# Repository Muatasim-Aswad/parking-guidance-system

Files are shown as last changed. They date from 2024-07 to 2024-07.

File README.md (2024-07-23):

# Parking Guidance System

The recent technological developments accompanied by economic changes have made affording an automobile easier and consequently led to a rapid increase in their numbers. Simultaneously, the usage of parking lots has increased. This increase is also concentrated due to people's tendency to populate certain small areas for different factors. For instance, in 2014 alone, 4 million cars parked in the ISPARK parking lot in the Fatih district/Istanbul. Usually, drivers do not directly find available parking spots and spend on average 7.8 to 10 minutes searching for them. Additionally, in large car parks, the driver might confront difficulties in finding the location of their parked car. This problem has adverse economic, environmental, and psychological effects. In the USA, the annual average time loss per driver during this process is 17 hours. Every time it costs a driver in France or the UK 1.42 Euro. The resulting emissions of CO2, CO, HC, and NOx are respectively 398.71, 19.90, 3.29, and 21.14 g/s/vehicle.

## The Design

As a solution to this problem, a prototype Parking Guidance System has been developed through the following. A conceptual design that addresses the system’s objectives, functions, guidance levels, and main components was prepared. The main criterion was to design a system that is more economical, less complex, flexible, scalable, and possible to improve while being acceptably efficient.

### System Components

- **Controller:** Arduino Mega (ATmega2560)
- **Sensors:** Ultrasonic sensors
- **Communication:** NodeMcu 12E (ESP8266) for Wi-Fi communication
- **User Interface:** Blynk IoT platform
- **Indicators:** Red and green LEDs, and an LCD 16x2

[Here](./drawings/fritzing/components-list.md) is the detailed list of the components.

The flow charts, block, pictorial, and schematic diagrams is used to describe the system processes, physical components, wiring, and their interactions. The code is written in Arduino IDE – C++ and preceded by flow charts that show all the functions and decision trees in the system software. Before successfully implementing the system, it was partially tested in a simulation environment, [Proteus](./drawings/proteus/) and [Wokwi](https://wokwi.com/projects/333014911768592980).

#### System Block Diagram

block diagram

#### System Flow Chart

flowchart

### Prototype Details

The prototype contains:

- 3 parking spaces with lamps
- A gate with a screen
- A website and an application through an IoT platform

The driver can see which spots are available in the parking lot through the screen, the app, and the website. While inside, they will be guided through the green lamps. Once the car is parked, the name (ID) of the car is assigned to the filled space. The ID can be chosen by the user through the Internet user interface (UI), otherwise, it would be chosen automatically by the system. Later the driver can locate his car by searching on the UI using the ID.

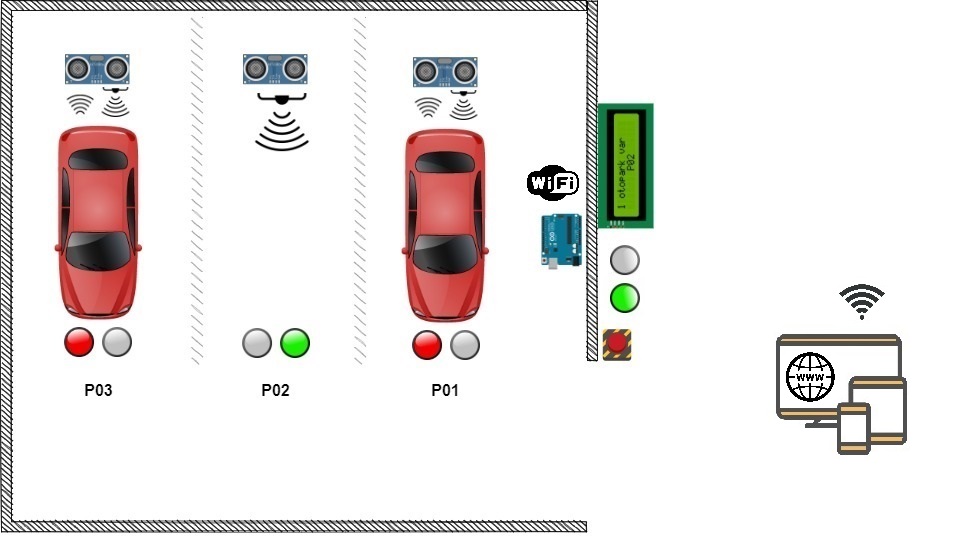
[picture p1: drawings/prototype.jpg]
prototype


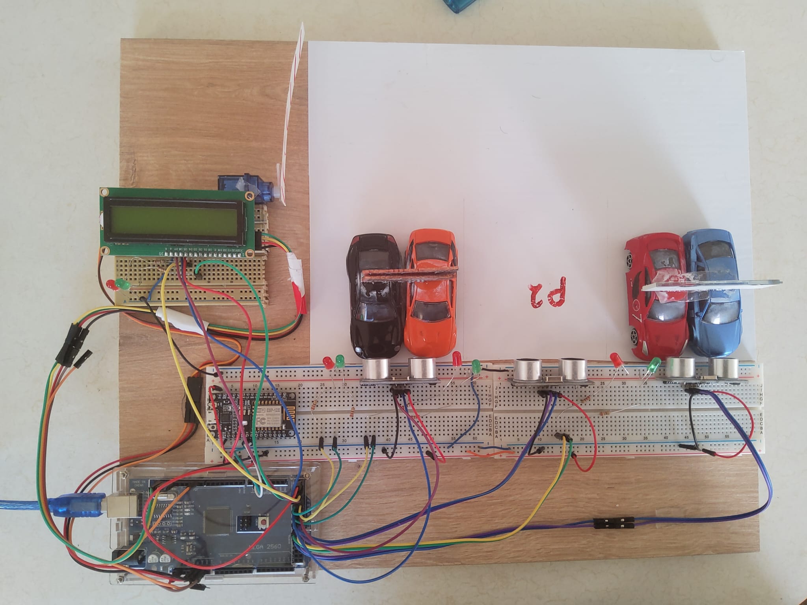
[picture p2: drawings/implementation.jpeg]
implementation


### Wiring

#### Pictorial Diagram

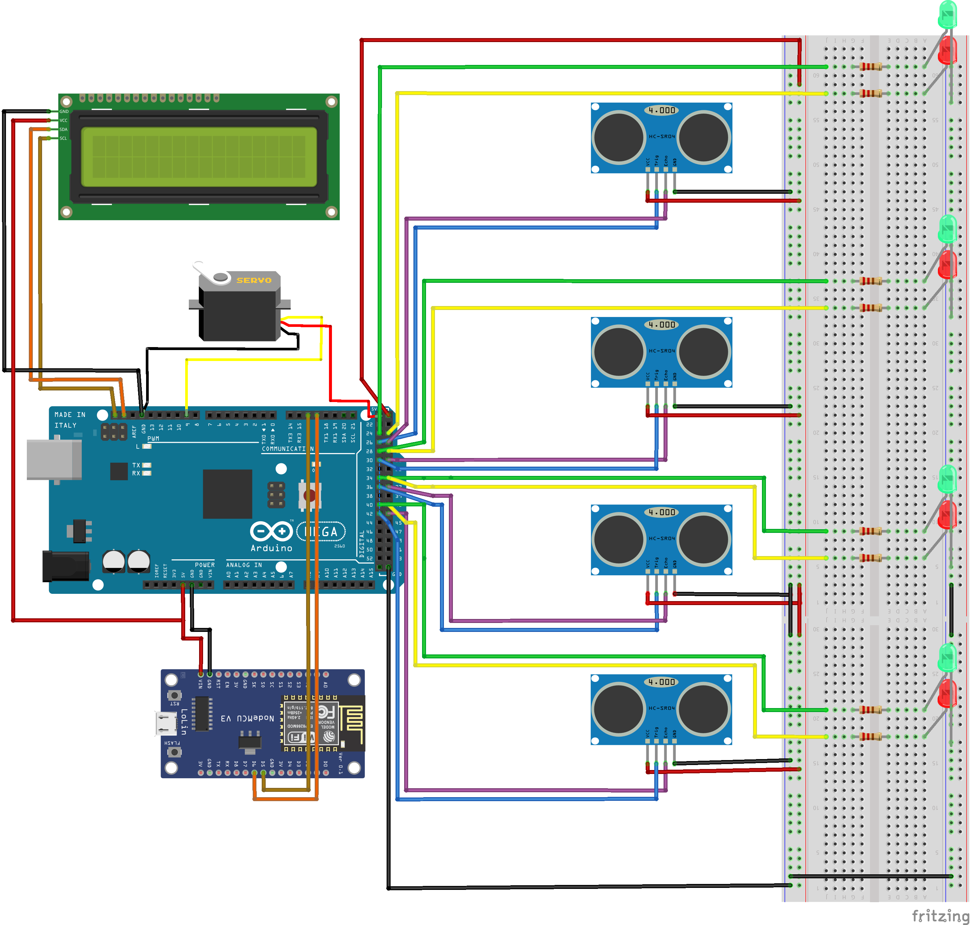
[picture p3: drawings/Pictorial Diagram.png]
Pictorial Diagram


#### Schematics - wires

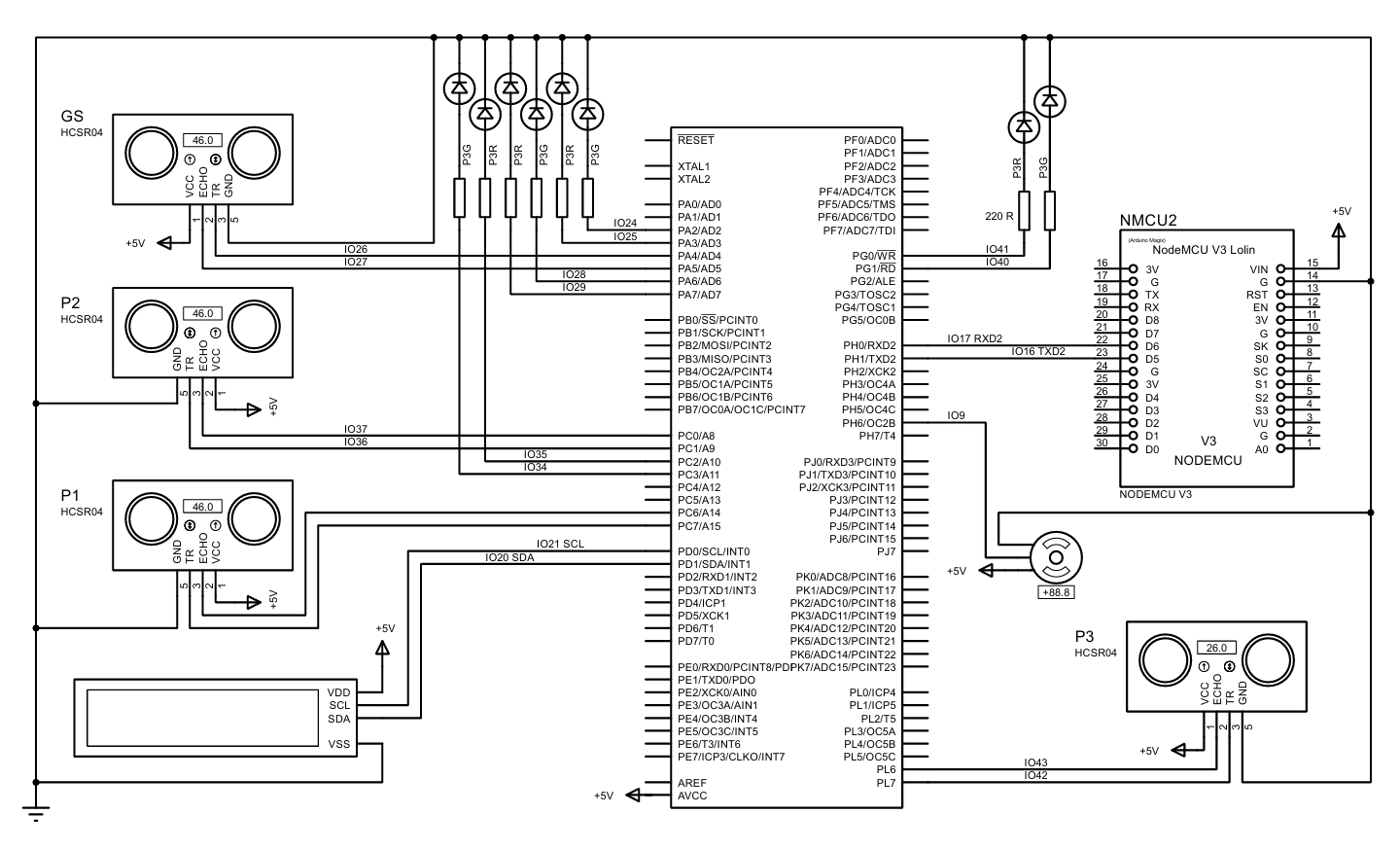
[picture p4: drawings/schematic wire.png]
Schematics - wires


#### Schematics - nodes

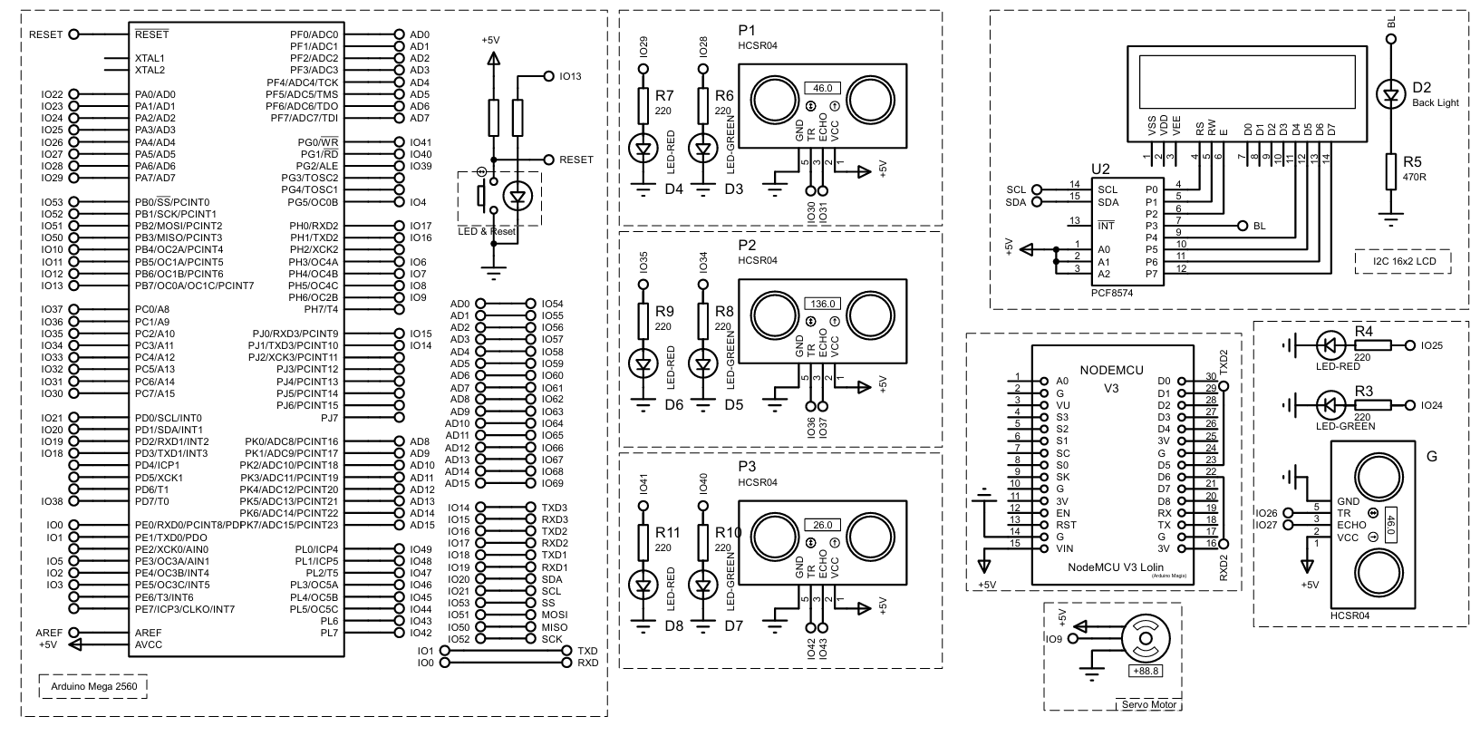
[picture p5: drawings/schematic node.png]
Schematics - nodes


### Future Improvements

- **Environmental Adaptation:** Sensors working with signals other than sound waves might be added to the already used sensors.
- **Automatic ID Registration:** Installing a plate reader on the gates to register the car number as its ID.
- **Enhanced Algorithm:** Improving the algorithm that assigns the car ID to the filled space for more accurate results.
- **User Interface Development:** Expanding the Internet user interface to include more features that benefit users on both sides, the owner, and the consumer.
- **City-Wide Guidance:** Integrating the system into a more comprehensive platform to guide the driver in larger areas, such as a whole city.
- **AI Integration:** Using AI algorithms to provide predictions about parking space availability and analyze user behavior.

### Ethical Considerations

The huge flow of data in automation processes dealing directly with consumers comes with the risk of violating user privacy. Therefore, adhering to ethical standards and legal regulations is essential for user rights. The implementation of these requirements should be observed and assured by the legal authorities.

## References

1. İSPARK, «Otoparklar her gün yoğun,» 6 Ocak 2015. [Çevrimiçi]. Available: [İspark](https://ispark.istanbul/)
2. O. Dokur, S. Katkoori and N. Elmehraz, «Embedded system design of a real-time parking guidance system,» Annual IEEE Systems Conference (SysCon), pp. 1-8, 2016.
3. Nandyal, Suvarna, Sabiya Sultana, and Sadaf Anjum., «Smart car parking system using arduino uno.,» International Journal of Computer Applications, no. 169.1, pp. 13-18, 2017.
4. Varan, Metin, and Ceylan Karakuş., «Sakarya şehri için dış ve iç yönlendirmeli rezervasyon tabanlı otopark yönetim sistemi tasarımı ve sistem başarımı,» Sakarya Üniversitesi Fen Bilimleri Enstitüsü Dergisi, cilt 1, no. 22, pp. 66-74, 2018.
5. P. D. M. Öztürk, «Otopark planlamasız şehirleşme olmaz,» 28 Şubat 2020. [Çevrimiçi]. Available: [Indyturk](https://www.indyturk.com/)
6. Dogaroglu, Bora, S. Pelin Caliskanelli, and Serhan Tanyel, «Comparison of intelligent parking guidance system and conventional system with regard to capacity utilisation.,» Sustainable Cities and Society, cilt 74, p. 103152, 2021.
7. Zhou, Fengli and Li, Qing, «Parking Guidance System Based on ZigBee and Geomagnetic Sensor Technology,» 2014 13th International Symposium on Distributed Computing and Applications to Business, Engineering and Science, pp. 268-271, 2014.
8. S.-e. Y. e. al, «PGS: Parking Guidance System based on wireless sensor network,» 2008 3rd International Symposium on Wireless Pervasive Computing, pp. 218-222, 2008.
9. H. V. Jaurkar, G. N. Mulay and V. Gohokar, «Parking guidance system using Internet of Things,,» International Conference on Inventive Computation Technologies (ICICT), cilt 1, pp. 1-6, 2016.
10. Huang, K. Y. and Chang, S. B. and Tsai, P. R., «The advantage of the arduino sensing system on parking guidance information systems,» 2017 IEEE International Conference on Industrial Engineering and Engineering Management (IEEM), Cilt %1 / %22078-2082, 2017.

## License

This is part of a project during my BSc in Mechatronics.

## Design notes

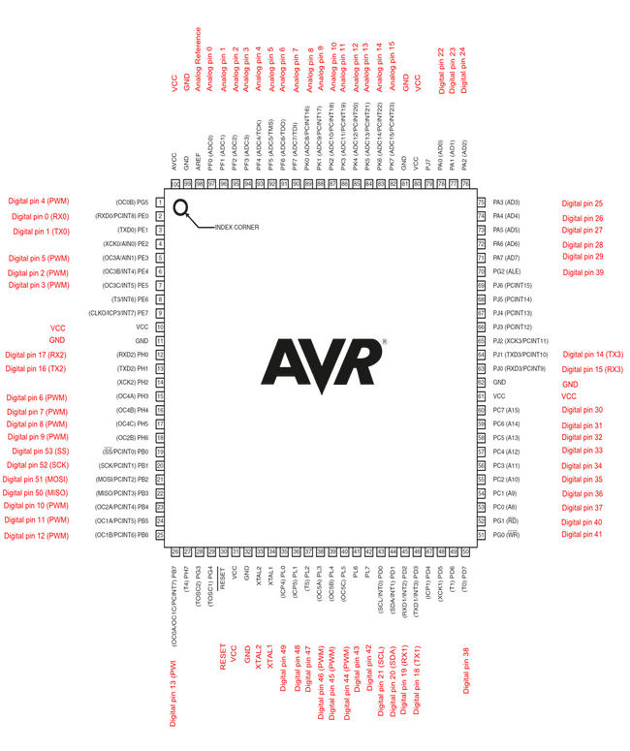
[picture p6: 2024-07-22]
datasheets/PinMap2560big_Rev2.png

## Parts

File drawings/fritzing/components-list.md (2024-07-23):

# Bill of Materials: otopark.fzz

*C:/Users/malas/Downloads/Bitirme/Fritzing/otopark.fzz*  
*Sunday, June 5 2022, 14:00:10*

## Assembly List

| Label | Part Type | Properties |
|---|---|---|
| hc-sr2 | hc-sr04 | variant hc-sr04 |
| hc-sr3 | hc-sr04 | variant hc-sr04 |
| hc-sr4 | hc-sr04 | variant hc-sr04 |
| hc-sr5 | hc-sr04 | variant hc-sr04 |
| J1 | Basic Servo |  |
| LED2 | Green (570nm) LED | color Green (570nm); leg yes; package 5 mm [THT] |
| LED3 | Red (635nm) LED | color Red (635nm); leg yes; package 5 mm [THT] |
| LED4 | Red (635nm) LED | color Red (635nm); leg yes; package 5 mm [THT] |
| LED5 | Green (570nm) LED | color Green (570nm); leg yes; package 5 mm [THT] |
| LED6 | Red (635nm) LED | color Red (635nm); leg yes; package 5 mm [THT] |
| LED7 | Green (570nm) LED | color Green (570nm); leg yes; package 5 mm [THT] |
| LED8 | Red (635nm) LED | color Red (635nm); leg yes; package 5 mm [THT] |
| LED9 | Green (570nm) LED | color Green (570nm); leg yes; package 5 mm [THT] |
| Part1 | Arduino Mega 2560 (Rev3) | type Arduino MEGA 2560 (Rev3) |
| Part2 | LCD1602-I2C | variant variant 1; pins 4; type Character |
| R1 | 220Ω Resistor | tolerance ±5%; package 2010 [SMD]; resistance 220Ω |
| R2 | 220Ω Resistor | tolerance ±5%; package 2010 [SMD]; resistance 220Ω |
| R3 | 220Ω Resistor | tolerance ±5%; package 2010 [SMD]; resistance 220Ω |
| R4 | 220Ω Resistor | tolerance ±5%; package 2010 [SMD]; resistance 220Ω |
| R5 | 220Ω Resistor | tolerance ±5%; package 2010 [SMD]; resistance 220Ω |
| R6 | 220Ω Resistor | tolerance ±5%; package 2010 [SMD]; resistance 220Ω |
| R7 | 220Ω Resistor | tolerance ±5%; package 2010 [SMD]; resistance 220Ω |
| R8 | 220Ω Resistor | tolerance ±5%; package 2010 [SMD]; resistance 220Ω |
| U1 | ESP8266 NodeMCU LoLin module | type ESP8266 NodeMCU LoLin |

## Shopping List

| Amount | Part Type | Properties |
|---|---|---|
| 4 | hc-sr04 | variant hc-sr04 |
| 1 | Basic Servo |  |
| 4 | Green (570nm) LED | color Green (570nm); leg yes; package 5 mm [THT] |
| 4 | Red (635nm) LED | color Red (635nm); leg yes; package 5 mm [THT] |
| 1 | Arduino Mega 2560 (Rev3) | type Arduino MEGA 2560 (Rev3) |
| 1 | LCD1602-I2C | variant variant 1; pins 4; type Character |
| 8 | 220Ω Resistor | tolerance ±5%; package 2010 [SMD]; resistance 220Ω |
| 1 | ESP8266 NodeMCU LoLin module | type ESP8266 NodeMCU LoLin |

*Exported with Fritzing 0.9.3 - [http://fritzing.org](http://fritzing.org)*

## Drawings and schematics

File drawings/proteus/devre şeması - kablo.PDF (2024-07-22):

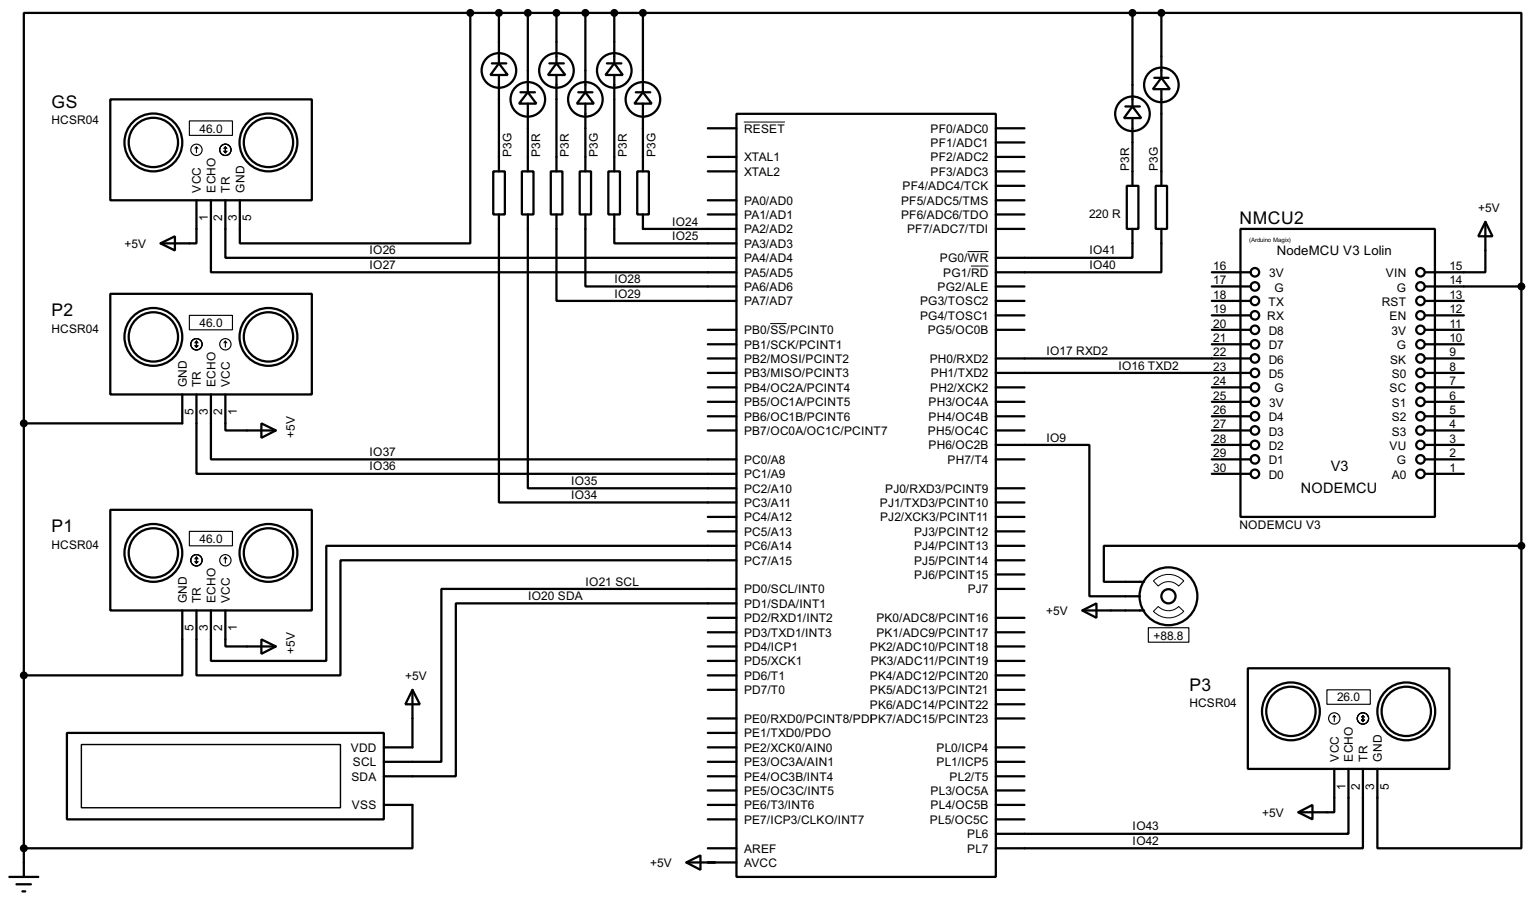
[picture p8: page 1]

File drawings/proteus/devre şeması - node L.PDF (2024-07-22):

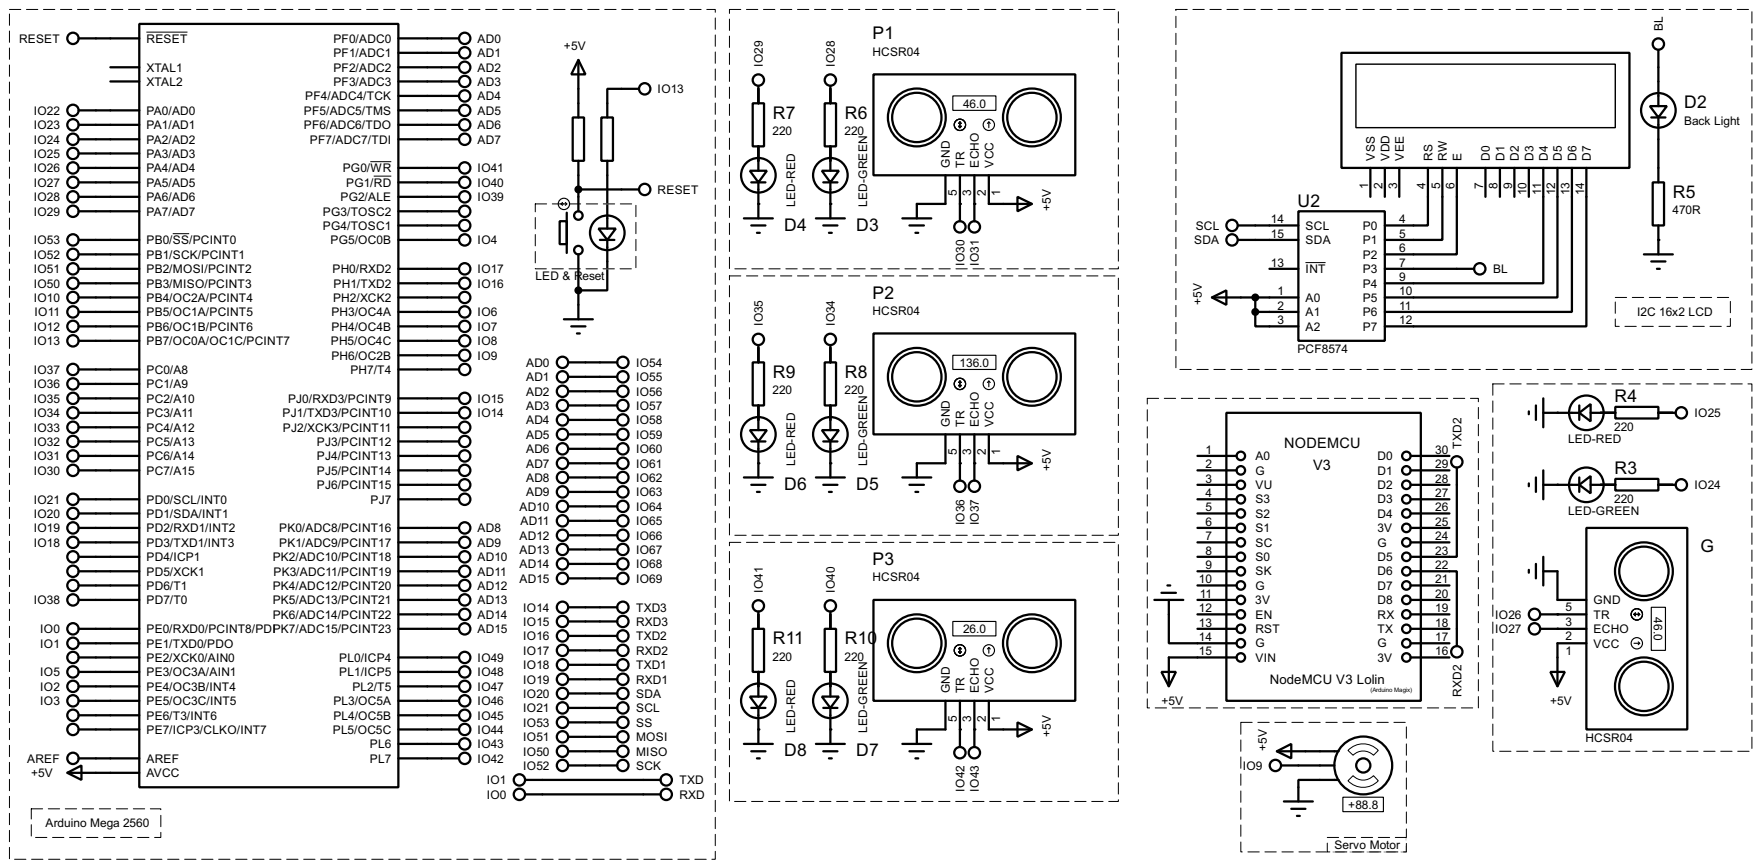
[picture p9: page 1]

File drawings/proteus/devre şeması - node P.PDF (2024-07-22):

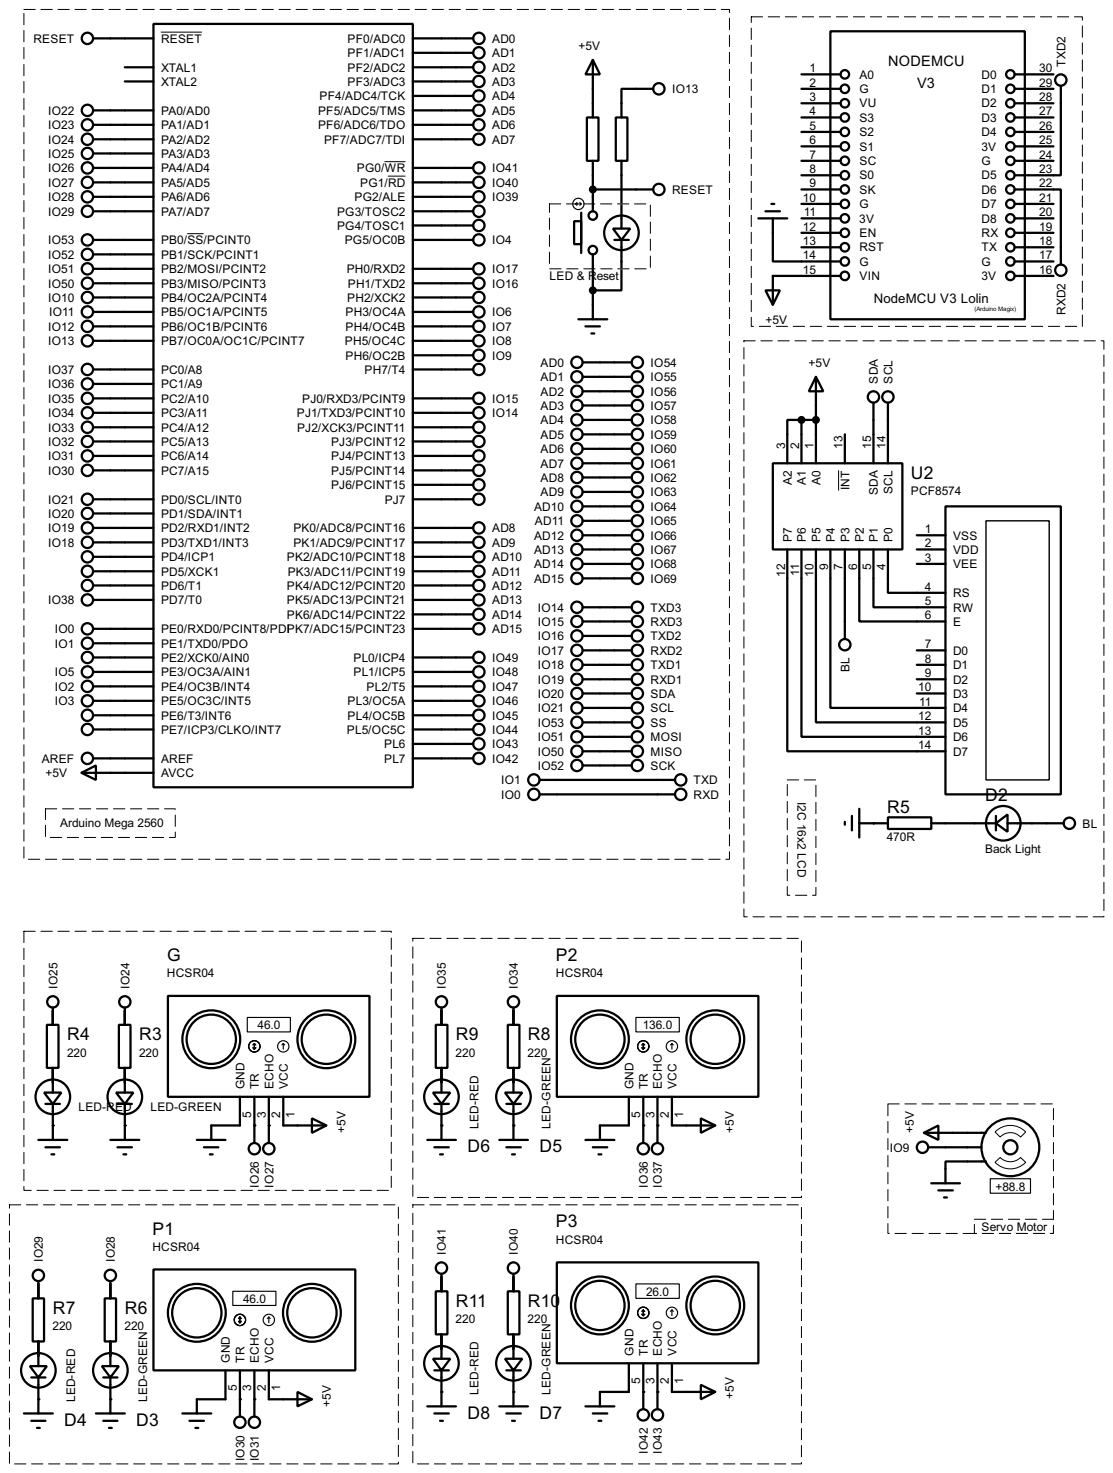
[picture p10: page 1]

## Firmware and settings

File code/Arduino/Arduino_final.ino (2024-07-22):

//---------------------------------------------------------------------------------------
// First, we define libraries and global variables.

#include <LiquidCrystal_I2C.h> // LCD and I2C communication library
#include <Servo.h>             // Servo motor library
#include <ArduinoJson.h>       // Library for serial communication with JSON variables

// Define pins for ultrasonic sensors and LEDs
const int gi_green = 24, gi_red = 25, gi_trig = 26, gi_echo = 27;
const int p1_green = 28, p1_red = 29, p1_trig = 30, p1_echo = 31;
const int p2_green = 34, p2_red = 35, p2_trig = 36, p2_echo = 37;
const int p3_green = 40, p3_red = 41, p3_trig = 42, p3_echo = 43;

LiquidCrystal_I2C lcd(0x27, 20, 21); // I2C address, SDA, and SCL pins

Servo myServo; // Define servo motor, pin: servo 9 or any PWM pin

int pos = 0; // Variable for servo motor position
int distance;

StaticJsonDocument<500> doc; // JSON object for serial communication

String idx, oldIDX; // Temporary ID for IoT or Arduino
String idh;         // ID of the current car
int FirstRun = 1;   // For initial setup

int old[3], p[3]; // Arrays for parking spot statuses
String place[3];  // Array to match IDs and parking spots

//---------------------------------------------------------------------------------------
// Setup function

void setup()
{
  pinMode(gi_trig, OUTPUT); // Set pin modes for each LED and ultrasonic sensor
  pinMode(gi_echo, INPUT);  // Input
  pinMode(gi_red, OUTPUT);
  pinMode(gi_green, OUTPUT);

  pinMode(p1_trig, OUTPUT); // Parking spot 1
  pinMode(p1_echo, INPUT);
  pinMode(p1_green, OUTPUT);
  pinMode(p1_red, OUTPUT);

  pinMode(p2_trig, OUTPUT); // Parking spot 2
  pinMode(p2_echo, INPUT);
  pinMode(p2_green, OUTPUT);
  pinMode(p2_red, OUTPUT);

  pinMode(p3_trig, OUTPUT); // Parking spot 3
  pinMode(p3_echo, INPUT);
  pinMode(p3_green, OUTPUT);
  pinMode(p3_red, OUTPUT);

  myServo.attach(9); // Pin for the servo motor
  myServo.write(0);  // Move to zero position

  Serial2.begin(115200); // Serial communication for Arduino

  lcd.init();                  // Initialize and start LCD
  lcd.backlight();             // LCD backlight
  lcd.print("Parking System"); // Display message on LCD
  delay(2000);
}

//---------------------------------------------------------------------------------------
// Main loop function

void loop()
{

  // Save old parking spot statuses
  for (byte i = 0; i < 3; i++)
  {
    old[i] = p[i];
  }

  // Update current parking spot statuses, 1 if full
  p[0] = IsItFull(p1_trig, p1_echo, p1_green, p1_red);
  p[1] = IsItFull(p2_trig, p2_echo, p2_green, p2_red);
  p[2] = IsItFull(p3_trig, p3_echo, p3_green, p3_red);

  int total = p[0] + p[1] + p[2]; // Sum of occupied spots

  // Define IDs if it's the first run
  if (FirstRun)
  {
    for (byte i = 0; i < 3; i++)
    {
      if (p[i] == 1)
        place[i] = String(i + 1);
    }
    FirstRun = 0;
  }

  // Check for changes in parking spot statuses
  Park_Situation_Change();

  // Send ID and parking status as JSON object to NodeMCU
  doc["ID1"] = place[0];
  doc["ID2"] = place[1];
  doc["ID3"] = place[2];

  serializeJson(doc, Serial2);
  delay(500);

  // Check entrance, update LCD, servo, LEDs, and ultrasonic sensor
  Entrance(total);
}

//---------------------------------------------------------------------------------------
// Function to detect parking spot status and control LEDs

int IsItFull(int trigPin, int echoPin, int greenLed, int redLed)
{
  distance = DistanceUltrasonic(trigPin, echoPin);
  if (distance > 9)
  {
    digitalWrite(greenLed, HIGH);
    digitalWrite(redLed, LOW);
  }
  else
  {
    digitalWrite(greenLed, LOW);
    digitalWrite(redLed, HIGH);
  }
  int status = digitalRead(redLed);
  return status;
}

//---------------------------------------------------------------------------------------
// Function to get distance using ultrasonic sensor

int DistanceUltrasonic(int trigPin, int echoPin)
{
  digitalWrite(trigPin, LOW); // Ensure a clean low signal
  delayMicroseconds(2);
  digitalWrite(trigPin, HIGH); // Send trigger pulse
  delayMicroseconds(10);
  digitalWrite(trigPin, LOW);
  long duration = pulseIn(echoPin, HIGH); // Measure pulse duration
  return duration * (0.034 / 2);          // Calculate distance
}

//---------------------------------------------------------------------------------------
// Function to check the entrance and control various devices

void Entrance(int total)
{
  if (total == 3)
  { // Parking is full
    digitalWrite(gi_red, HIGH);
    digitalWrite(gi_green, LOW);
    lcd.clear();
    lcd.print("Parking Full");
    lcd.setCursor(0, 1);
    lcd.print("   0 full 0   ");
    delay(500);
  }
  else
  { // Parking has space
    digitalWrite(gi_red, LOW);
    digitalWrite(gi_green, HIGH);
    lcd.clear();
    lcd.setCursor(0, 0);
    lcd.print(3 - total);
    lcd.print(" spots available");

    lcd.setCursor(0, 1); // Display empty parking spots on LCD
    for (byte i = 0; i < 3; i++)
    {
      if (p[i] == 0)
      {
        lcd.print("  P0");
        lcd.print(i + 1);
      }
      else
      {
        lcd.print("     ");
      }
    }
    delay(500);
    CheckEntrance(gi_trig, gi_echo); // Check if a car is at the entrance
  }
}

//---------------------------------------------------------------------------------------
// Function to check if a car is at the entrance and perform necessary actions

void CheckEntrance(int trigPin, int echoPin)
{
  distance = DistanceUltrasonic(trigPin, echoPin);
  if (distance < 6)
  {
    lcd.clear();
    lcd.setCursor(0, 0);
    lcd.print("Please wait");
    lcd.setCursor(0, 1);
    lcd.print("Enter ID in Blynk");
    RecieveID(trigPin, echoPin); // Get the user's ID from NodeMCU
    if (distance < 6)
    {
      DefineID(); // Define the ID
      lcd.clear();
      lcd.print(idh);
      lcd.setCursor(0, 1);
      lcd.print(" can enter");
      OpenEntrance(); // Open the entrance gate
      while (distance < 8)
      { // Wait until the car moves
        distance = DistanceUltrasonic(trigPin, echoPin);
      }
      delay(1000);
      CloseEntrance(); // Close the entrance gate
    }
  }
  else if (pos != 0)
  { // If the entrance gate is not closed, close it
    CloseEntrance();
  }
}

//---------------------------------------------------------------------------------------
// Function to receive the user's ID from NodeMCU

void RecieveID(int trigPin, int echoPin)
{
  for (byte i = 0; i < 20; i++)
  { // Wait approximately 20 seconds
    delay(1000);
    DeserializationError error = deserializeJson(doc, Serial2);

    oldIDX = idx;
    if (!error && oldIDX != doc["IDX"])
    { // Get IDX from NodeMCU
      idx = doc["IDX"].as<String>();
      delay(500);
    }
    distance = DistanceUltrasonic(trigPin, echoPin);
    if (distance > 8)
      break;
    if (idx != oldIDX) // Exit loop if ID is received
      break;
  }
}

//---------------------------------------------------------------------------------------
// Function to define the ID, automatically if not provided by the user
// Ensures the ID is unique and a parking spot is available

void DefineID()
{
  int y = 0;
  if (idx == oldIDX)
    idx = "0";

  while (idx == "0")
  { // Create a unique ID
    y++;
    String x = String(y);
    for (byte i = 0; i < 3; i++)
    {
      if (place[i] == x)
      {
        idx = "0";
        break;
      }
      else
      {
        idx = x;
      }
    }
  }
  idh = idx;
}

//---------------------------------------------------------------------------------------
// Function to open the gate

void OpenEntrance()
{
  for (pos; pos <= 90; pos += 1)
  {
    myServo.write(pos);
    delay(15);
  }
}

//---------------------------------------------------------------------------------------
// Function to close the gate

void CloseEntrance()
{
  for (pos; pos >= 0; pos -= 1)
  {
    myServo.write(pos);
    delay(15);
  }
}

//---------------------------------------------------------------------------------------
// Function to update the ID and parking spot arrays when parking spot status changes

void Park_Situation_Change()
{
  for (byte i = 0; i < 3; i++)
  {
    if (p[i] != old[i])
    {
      if (p[i] == 1)
      {
        place[i] = idh;
        idh = "undefined";
      }
      else
      {
        place[i] = "0";
      }
    }
  }
}

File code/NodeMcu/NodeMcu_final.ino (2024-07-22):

/*---------------------------------------------------------------------------------------
Definitions and Libraries*/

#define BLYNK_TEMPLATE_ID           "TMPLHz-2F1jH"  /* Definitions for connecting with Blynk */
#define BLYNK_DEVICE_NAME           "OtoPark"
#define BLYNK_AUTH_TOKEN            "****"
#define BLYNK_PRINT Serial

#include <ESP8266WiFi.h> /* For NodeMCU WiFi */
#include <BlynkSimpleEsp8266.h>

#include <SoftwareSerial.h> /* For serial communication with Arduino */
#include <ArduinoJson.h>    /* For sending and receiving data in JSON format */

SoftwareSerial nodemcu(D5, D6); /* RX, TX must be connected inversely with Arduino */

char auth[] = BLYNK_AUTH_TOKEN; 
char ssid[] = "****"; /* WiFi name and password */
char pass[] = "****";

BlynkTimer timer;

String IDX, ID1, ID2, ID3; /* Variables for communication via NodeMCU */
StaticJsonDocument<1000> doc; /* Define JSON object */

/*---------------------------------------------------------------------------------------
Always Active Function*/

WidgetTerminal terminal(V0);  /* Function that will be triggered when an ID is entered in Blynk */
BLYNK_WRITE(V0)
{
 /* If the ID is already used, specify the parking spot; if the ID is new, request a different ID */
 if (ID1 == param.asStr())      
    terminal.println("In Parking Spot 1, select a different ID if the car is entering");
 else if (ID2 == param.asStr())
    terminal.println("In Parking Spot 2, select a different ID if the car is entering");
 else if (ID3 == param.asStr())
    terminal.println("In Parking Spot 3, select a different ID if the car is entering");
 else { /* Send the ID to Arduino */
  IDX = param.asStr();
  doc["IDX"] = IDX;
  serializeJson(doc, nodemcu);
  Serial.print(IDX);
  terminal.println(IDX);
  terminal.println("ID sent to parking system");
  }    
 terminal.flush();
}

/*---------------------------------------------------------------------------------------
Setup Function*/

void setup()
{
  //Serial.begin(115200);
  
  Blynk.begin(auth, ssid, pass);
  terminal.clear();

  nodemcu.begin(115200); 
}

/*---------------------------------------------------------------------------------------
Main Function*/

void loop()
{
  Blynk.run();
  timer.run();

  /* Get parking spot IDs from Arduino */
  DeserializationError error = deserializeJson(doc, nodemcu);
  
  if (!error){
  /* Get IDs from JSON */
  ID1 = doc["ID1"].as<String>();
  ID2 = doc["ID2"].as<String>();
  ID3 = doc["ID3"].as<String>();

  /* Send IDs to Blynk */
  Blynk.virtualWrite(V1, ID1);
  Blynk.virtualWrite(V2, ID2);
  Blynk.virtualWrite(V3, ID3);
  }
}
